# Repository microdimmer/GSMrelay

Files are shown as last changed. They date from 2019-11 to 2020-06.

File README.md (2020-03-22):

# Arduino GSM relay with ring controlling and temp sensors

GSM relay with two temperature sensors, GSM time-synchronization, ring controlling and audio notification. 

## Components

* GSM/GPRS AiThinker A6 
* Arduino Pro Mini, Atmega 328p, 5V/16MHz
* I2C 1602 16X2 Character LCD Module
* Two ds18b20 temperature sensors
* DFPlayer mini MP3 module
* Relay module
* Rotary encoder switch EC11
* Resistors, wires, enclosure

## Photos:


## Libraries

* [Arduino](https://github.com/arduino/Arduino)
* [Forked menu library for 1602](https://github.com/microdimmer/LiquidMenu)
* [I2C support for 1602](https://github.com/johnrickman/LiquidCrystal_I2C)
* [Memory free library for debuging](https://github.com/maniacbug/MemoryFree)
* [Simple timer library](https://github.com/marcelloromani/Arduino-SimpleTimer)
* [Timekeeping library](https://github.com/PaulStoffregen/Time)
* [Library to handle rotary encoder with button](https://github.com/0xPIT/encoder)
* [DFPlayer mini module library](https://github.com/DFRobot/DFRobotDFPlayerMini)
* [OneWire library](https://github.com/PaulStoffregen/OneWire)

## Scheme:
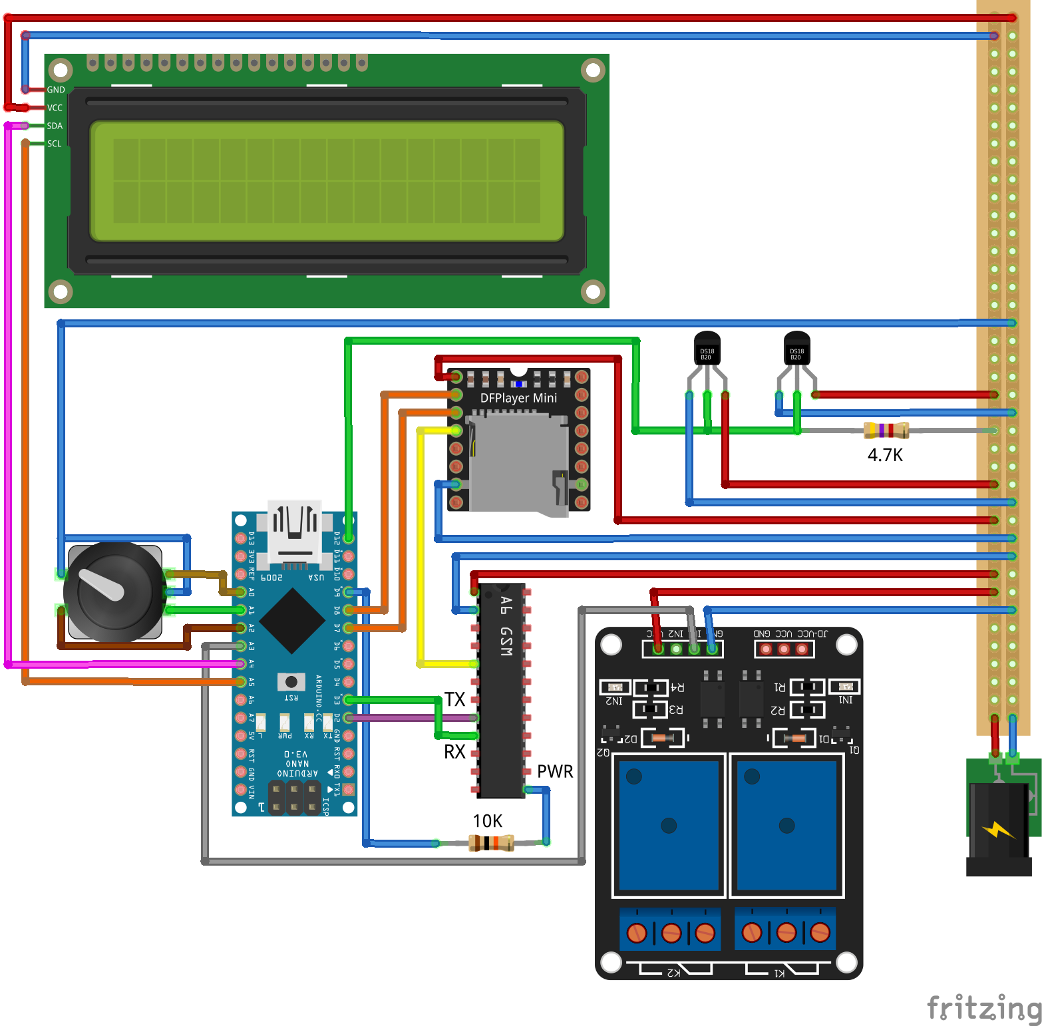
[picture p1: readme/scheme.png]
СХЕМА


## Known issues:

* Relay creates electromagnetic interference which affects the I2C display driver, had to install ferrite bead on I2C data wires.

# Russian:
GSM реле c термостатом, двумя датчиками температуры, автоматизацией по температуре, активацией по телефону и аудио оповещениями.

## Компоненты

* Плата GSM/GPRS AiThinker A6 
* Arduino Pro Mini, Atmega 328p, 5V/16MHz
* Монохромный дисплей I2C 1602 16X2 Character LCD
* Датчик температуры ds18b20 x2
* Модуль воспроизведения MP3 DFPlayer mini 
* Реле 5v
* Энкодер с кнопкой EC11
* кнопки, резисторы, провода, корпус

## Библиотеки

* [Arduino](https://github.com/arduino/Arduino)
* [Forked menu library for 1602](https://github.com/microdimmer/LiquidMenu)
* [I2C support for 1602](https://github.com/johnrickman/LiquidCrystal_I2C)
* [Memory free library for debuging](https://github.com/maniacbug/MemoryFree)
* [Simple timer library](https://github.com/marcelloromani/Arduino-SimpleTimer)
* [Timekeeping library](https://github.com/PaulStoffregen/Time)
* [Library to handle rotary encoder with button](https://github.com/0xPIT/encoder)
* [DFPlayer mini module library](https://github.com/DFRobot/DFRobotDFPlayerMini)
* [OneWire library](https://github.com/PaulStoffregen/OneWire)

## Известные проблемы:

* При переключении GSM-реле на дисплее наблюдались крякозябры из-за электромагнитных помех, пришлось поставить ферритовый фильтры на шину I2C.

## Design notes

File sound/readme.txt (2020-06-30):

1			0001.mp3
2			0002.mp3
3			0003.mp3
4 			0004.mp3
5 			0005.mp3
6 			0006.mp3
7 			0007.mp3
8 			0008.mp3
9 			0009.mp3
10 			0010.mp3
11  		0011.mp3
12			0012.mp3
13			0013.mp3
14			0014.mp3
15			0015.mp3
16			0016.mp3
17			0017.mp3
18			0018.mp3
19			0019.mp3
20			0020.mp3
30			0021.mp3
40			0022.mp3
50			0023.mp3
60			0024.mp3
70			0025.mp3
80			0026.mp3
90			0027.mp3
zero		0028.mp3
minus		0029.mp3
plus		0030.mp3
degree		0031.mp3
degrees		0032.mp3
degrees		0033.mp3
on			0034.mp3 -	джэ эс эм реле привЕтствует! васссс. Вы активировали включение радиатора. Включаем.
off			0035.mp3 -	джэ эс эм реле привЕтствует! васссс. Вы активировали отключение радиатора. Выключаем.
temp_heater 0036.mp3
temp_house 	0037.mp3
balance 	0038.mp3
ruble	 	0039.mp3
rubles		0040.mp3
rubles		0041.mp3
signal_q-ty 0042.mp3
percent 	0043.mp3
percents 	0044.mp3
percents 	0045.mp3
100		 	0046.mp3
200		 	0047.mp3
300		 	0048.mp3
400		 	0049.mp3
500		 	0050.mp3
600		 	0051.mp3
700		 	0052.mp3
800		 	0053.mp3
900		 	0054.mp3
thermos_on  0055.mp3
thermos_off	0056.mp3

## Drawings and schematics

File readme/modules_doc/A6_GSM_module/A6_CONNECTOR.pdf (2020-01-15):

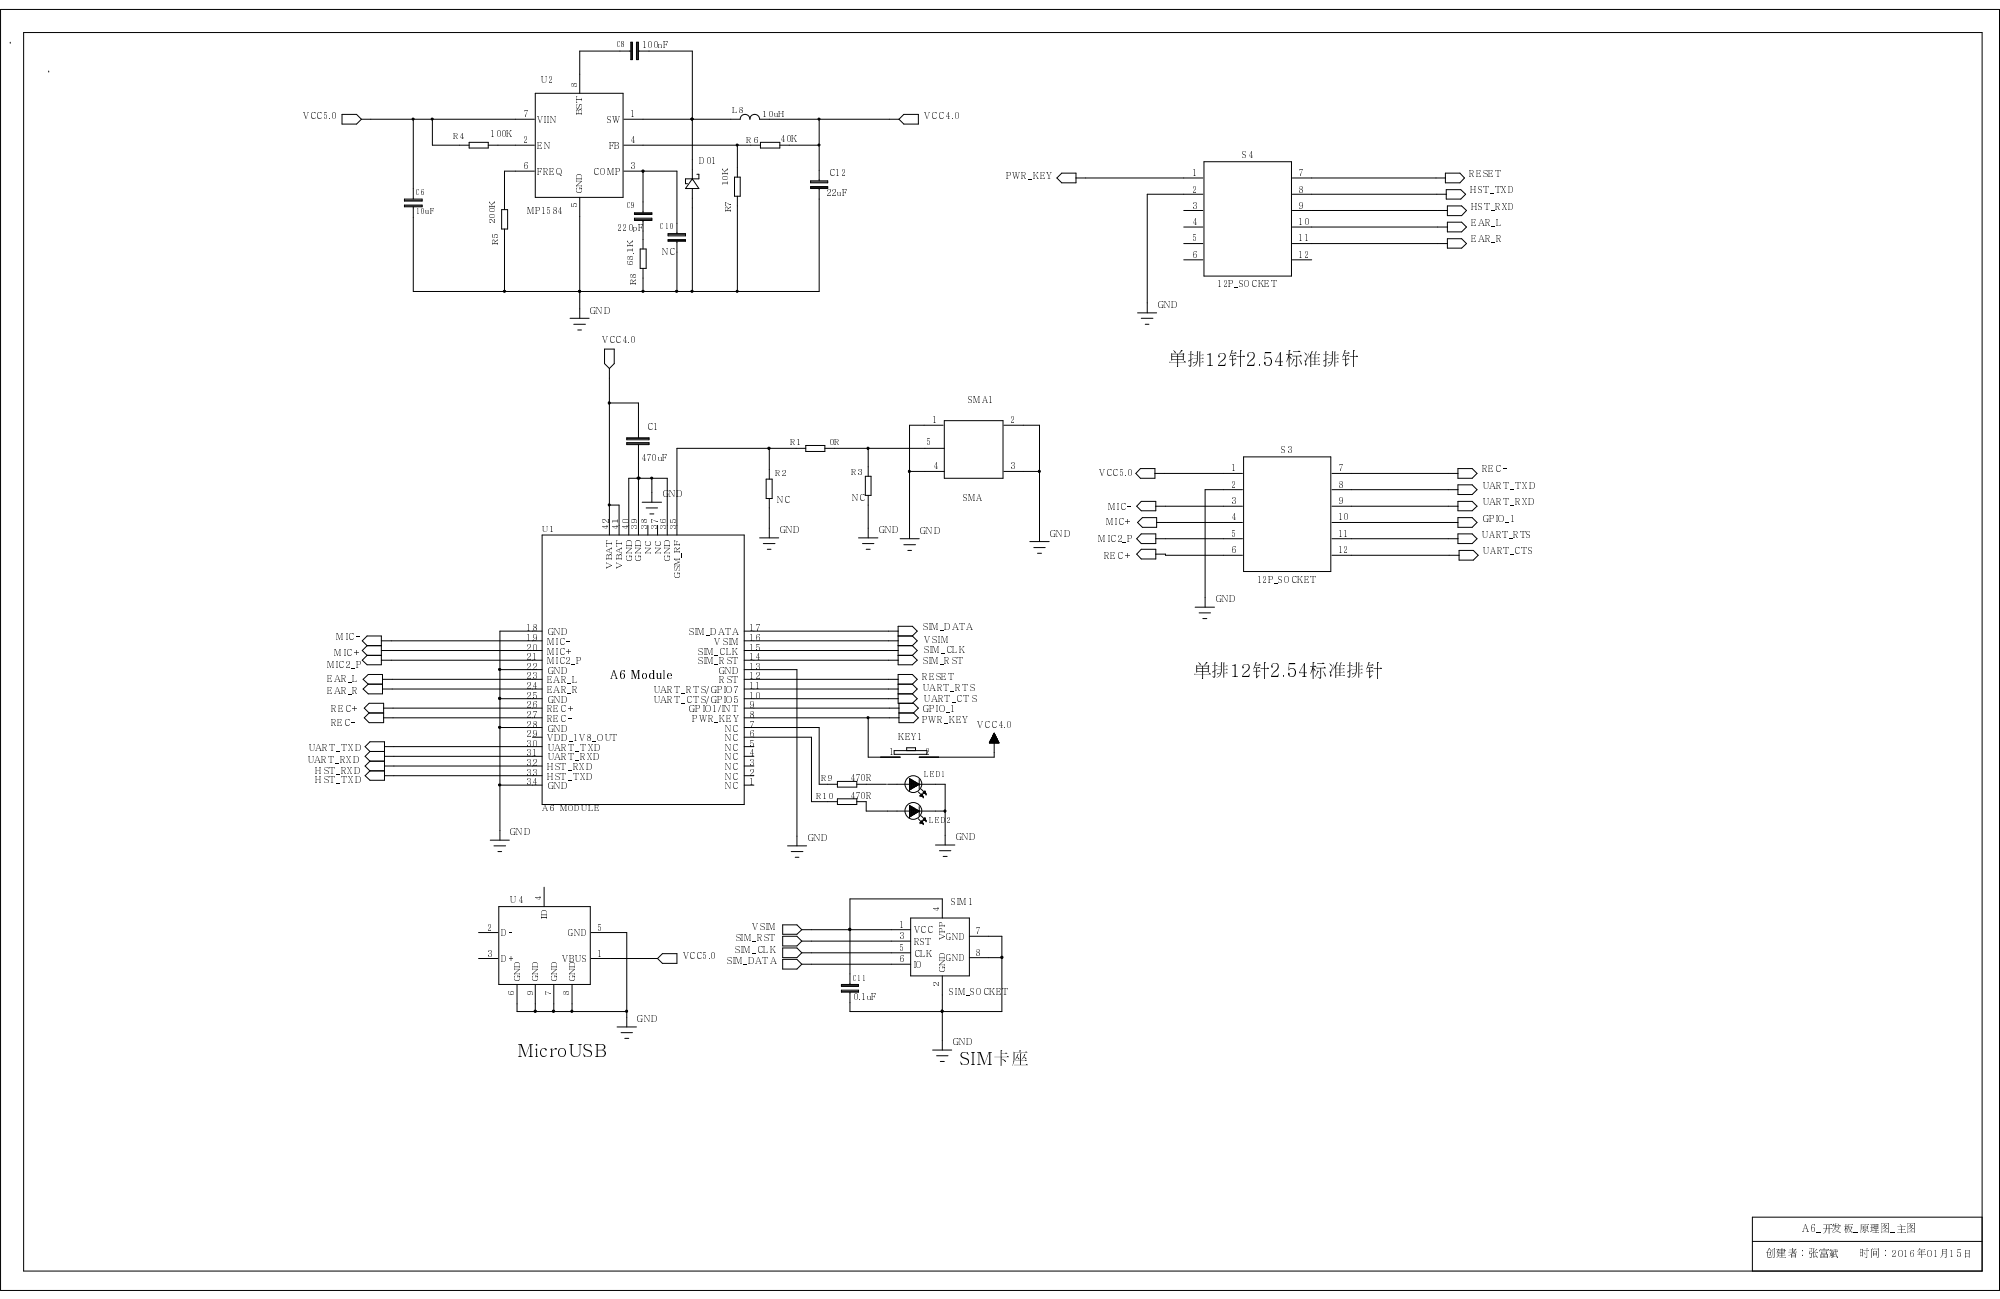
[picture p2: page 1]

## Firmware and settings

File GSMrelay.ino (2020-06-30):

//use DFPlayerMini_Fast, +
//add voice temp information, add read BUSY pin +
//add shedule and temp automation, 
//add preferences menu section, 

//!!!!edit LiquidMenu_config.h first!!!!
/// Configures the number of available variables per line.
// const uint8_t MAX_VARIABLES = 2; ///< @note Default: 5
// /// Configures the number of available functions per line.
// const uint8_t MAX_FUNCTIONS = 1; ///< @note Default: 8
// /// Configures the number of available lines per screen.
// const uint8_t MAX_LINES = 2; ///< @note Default: 12
// /// Configures the number of available screens per menu.
// const uint8_t MAX_SCREENS = 3; ///< @note Default: 14
// /// Configures the number of available menus per menus system.
// const uint8_t MAX_MENUS = 3; ///< @note Default: 8

#define DEBUGGING

const char PROG_VERSION = '3';
const uint8_t RELAY_PIN = A3;                                                                             //pin for Relay
const uint8_t GSM_PIN = 9;                                                                              //pin for GSM
const uint8_t TEMP_SENSOR_PIN = 12;                                                                     //pin for DS18B20
const uint8_t ENCODER_PIN1 = A1;                                                                        //pin for encoder +
const uint8_t ENCODER_PIN2 = A0;                                                                        //pin for encoder -
const uint8_t ENCODER_PIN3 = A2;                                                                        //pin for encoder button
const uint8_t GSM_SERIAL_RX = 2;                                                                        //pin for GSM serial
const uint8_t GSM_SERIAL_TX = 3;                                                                        //pin for GSM serial
const uint8_t MP3_SERIAL_RX = 4;                                                                        //pin for mp3 serial
const uint8_t MP3_SERIAL_TX = 5;                                                                        //pin for mp3 serial
const uint8_t MP3_BUSY = 7;                                                                             //mp3 busy pin
const char PHOME_NUM1[] PROGMEM = {"79227754426"};
const char PHOME_NUM2[] PROGMEM = {"79044719617"};                                                   //pap
const char PHOME_NUM3[] PROGMEM = {"79822219033"};                                                   //pap
const char PHOME_NUM4[] PROGMEM = {"79226505965"};                                                   //tat
const char *const phone_table[] PROGMEM = {PHOME_NUM1, PHOME_NUM2, PHOME_NUM3, PHOME_NUM4}; // phones table 

#include <MemoryFree.h> //https://github.com/maniacbug/MemoryFree TODO del
#include <CircularBuffer.h> // https://github.com/rlogiacco/CircularBuffer //TODO del
#include <OneWire.h>             //for DS18B20
// #include <DFRobotDFPlayerMini.h> //DF MP3 Player mini
#include <DFPlayerMini_Fast.h> //DFPlayer MP3 mini https://github.com/scottpav/DFPlayerMini_Fast
#include <ClickEncoder.h>   //encoder with button https://github.com/0xPIT/encoder
#include <TimeLib.h>        //timekeeping https://github.com/PaulStoffregen/Time
#include <SoftwareSerial.h> //for GSM modem A6 and MP3 module 
#include <SimpleTimer.h>    // Handy timers with callback parameters and polling https://github.com/marcelloromani/Arduino-SimpleTimer
#include <LiquidMenu.h>     //The menu wrapper library https://github.com/microdimmer/LiquidMenu and https://github.com/AlexGyver/GyverLibs/tree/master/microLiquidCrystal_I2C and https://github.com/AlexGyver/GyverLibs/tree/master/microWire
#include <EEPROM.h>         //saving log data to EEPROM and send SMS every 2.5 month

struct Log {
  int8_t home_temp; // temp +- 63, 1 byte, and sentinel, see this https://sites.google.com/site/dannychouinard/Home/atmel-avr-stuff/eeprom-longevity
  int8_t heater_temp; // heater +- 128, 1 byte
  int16_t balance; // balance +-32967, 2 bytes
  time_t unix_time; // current POSIX time, 4 bytes
}; //total 8 bytes (64 bits)

struct Prefs {
  int8_t t_home_set; // temp +- 63, 1 byte, and sentinel, see this https://sites.google.com/site/dannychouinard/Home/atmel-avr-stuff/eeprom-longevity
  int8_t t_heater_set; // heater +- 63, 1 byte, and thermostat flag
  int8_t t_home_hysteresis_set; // home hysteresis +- 128, 1 byte
  int8_t t_heater_hysteresis_set; // heater hysteresis +- 128, 1 byte
}; //total 4 bytes (32 bits)

#define LOGEEPROMSIZE E2END+1 - 256// sizeof(struct Log)*4 = 64*4 = 256;  EEPROM.length() is equal E2END+1

OneWire ds(TEMP_SENSOR_PIN);
byte DSaddr[2][8]; // first and second DS18B20 addresses, home 28FFE44750170473 heater 28FF2FDAC11704DE

ClickEncoder encoder(ENCODER_PIN1, ENCODER_PIN2, ENCODER_PIN3, 2); //changed to 2 at one turn
ClickEncoder::Button button;
int16_t last_val = 0;
int16_t enc_val = 0;

SoftwareSerial gsmSerial(GSM_SERIAL_RX, GSM_SERIAL_TX);
SoftwareSerial mp3Serial(MP3_SERIAL_RX, MP3_SERIAL_TX);
DFPlayerMini_Fast mp3Player;
// DFRobotDFPlayerMini mp3Player;
SimpleTimer timer;
LiquidCrystal_I2C lcd(0x3F, 16, 2);

char GSMstring[64] = {'\0'}; //GSM read string buffer
char string_buff[8] = {'\0'}; //string buffer, used for showing info on display
char phone_buff[12] = {'\0'} ; //phone number string
int8_t temp[2] = {-99, -99}; // temp home, temp heater
int8_t temp_set[2] = {25, 70}; // temp home to set, temp heater to set
int8_t temp_set_hysteresis[2] = {2, 10}; // temp home to set, temp heater to set
int8_t signalStrength = 0; //GSM signal strength
bool GSMonAirFlag = false; //answer call flag
bool GSMwaitReqFlag = false; // waiting request command flag
uint8_t readResponseCounter = 0; // count response commands to run, max 20 times x 500ms
const uint8_t readResponseNum = 20;  //limit 20 times to wait
const uint16_t readResponseTimeout = 500;  //responce timeout to wait
int16_t backlightTimerID = 0;

uint16_t memoryFree = 0;
int16_t balance = -32768; //min uint
CircularBuffer<uint8_t,18> audioQueue;     // audio sequence size, can play five files continuously CircularBuffer<uint8_t,6> audioQueue;
bool workFlag = false;
bool relayFlag = false;
bool thermostatFlag = false; 
bool backlightFlag = true;
bool updateMainScreenFlag = true;
bool clearMainSreenFlag = false;
bool SIMreadyOK = false;
bool GSMinitOK = false;
bool timeSyncOK = false;
bool signalSyncOK = false;
bool balanceSyncOK = false;
bool blinking = true;
uint8_t currentMenu = 0; //0 - homepage, 1 - main menu, 2 - info menu, 3 - temp menu, 4 - set params

#include "menu.h"
#include "debug.h"

void jobThermostat() {
  if (!thermostatFlag || !workFlag)
    return;

  for (uint8_t i = 0; i <= 1; i++) {
    if (temp_set[i] - temp[i] >= temp_set_hysteresis[i]) {
      relayFlag = true;
      digitalWrite(RELAY_PIN, relayFlag);
      PRINTLNF("relay on");
    }
    else {
      relayFlag = false;
      digitalWrite(RELAY_PIN, relayFlag);
      PRINTLNF("relay off");
    }
  }
}

void setup() {
  #ifdef DEBUGGING
  Serial.begin(9600);
  PRINTLNF("Debug on");
  #endif
  
  pinMode(RELAY_PIN, OUTPUT);
  digitalWrite(RELAY_PIN, relayFlag); //relay OFF

  initMenu();
  initMP3(); //mp3 serial port by default is not listening
  initGSM(); //init GSM module, the last intialized port is listening
  initDS();  //init DS temp modules
  requestTempUpdateScreen();  //request temp

  timer.setInterval(1000, requestTempUpdateScreen); //request temp once a second and update screen //TODO separate
  backlightTimerID = timer.setInterval(SECS_PER_MIN * 10000L, backlightOFF); //auto backlight off 10 mins
  
  if (!GSMinitOK) {
    lcd.clear();
    return;
  }
    
  requestBalance();  //request balance from GSM
  waitAndReadUntilOK(balanceSyncOK); //read data response
  requestSignalAndRAM();  //request signal quality from GSM
  waitAndReadUntilOK(signalSyncOK); //read data response
  requestTime(); //request time from GSM
  waitAndReadUntilOK(timeSyncOK); //read data response
  readDSresponse(); //read temp data response
  sendSMSBalance(); //check if its needed to send SMS and then send

  timer.setInterval(10000L, requestSignalAndRAM);        //request signal quality every 10 secs
  timer.setInterval(10000L, jobThermostat);        //do thermostat job
  timer.setInterval(SECS_PER_HOUR * 6000L, requestTime); //sync time every 6 hours
  timer.setInterval(SECS_PER_DAY * 80L, sendSMSBalance); //send sms with balance every 80 days
  timer.setInterval(SECS_PER_HOUR * 6000L, requestBalance);//request balance every 6 hours

  readStringGSM();
  lcd.clear();
  drawMainSreen();
}

void loop() {
  timer.run();
  readButton();
  readEncoder();
  drawMainSreen();
  readStringGSM();
}

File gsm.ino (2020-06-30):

void initGSM() {//TODO
 
  gsmSerial.setTimeout(100); // sets the maximum number of milliseconds to wait for readString()
  
  memset(GSMstring,0,sizeof(GSMstring));
  GSMstring[0] = '\0';
  lcd.setCursor(11, 1);

  #ifdef DEBUGGING
  gsmSerial.begin(9600);
  PRINTINFO("already initialized?");


  for (uint8_t i = 0; i < 4; i++)  {
    gsmSerial.println(F("AT")); 	
    loadingAnimation();
    gsmSerial.println(F("ATE0")); //echo off
    if (gsmSerial.find(strcpy_P(string_buff, PSTR("OK")))) {//copy PROGMEM to buff and find answer in GSM serial
      PRINTLNF("AT ok");
      GSMinitOK = true;
      loadingAnimation();

      gsmSerial.println(F("AT+CSCS=\"HEX\"")); // "GSM","HEX","PCCP936","UCS2
      loadingAnimation();

      cleanSerialGSM();
      return;
    }
  }
  #endif
  
  PRINTINFO("switching GSM");
  pinMode(GSM_PIN, OUTPUT);
  digitalWrite(GSM_PIN, LOW);
  loadingAnimation(4); //wait 2 sec
  digitalWrite(GSM_PIN, HIGH);

  PRINTLNF("");
  PRINTLNF("trying to set 9600");
  gsmSerial.begin(115200);
  for (size_t i = 0; i < 4; i++) {
    gsmSerial.println(F("AT+IPR=9600")); //trying to set 9600
    delay(50);
  }
  gsmSerial.begin(9600);
  
  cleanSerialGSM();
  PRINTINFO("initialize GSM");  
  for (uint8_t i = 0; i < 20; i++) {
    gsmSerial.println(F("AT+CPAS"));
    loadingAnimation();// display loading animation
    gsmSerial.println(F("ATE0")); //echo off
    // gsmSerial.readBytesUntil('\n', GSMstring, sizeof(GSMstring));
    // if (strstr_P(GSMstring, PSTR("+CPAS:0")) != NULL) {
    //   PRINTLNF("AT ok");
    //   GSMinitOK = true;
    //   break;
    // }
    // else {
    //   PRINTLN("GSMstring=",GSMstring);
    // }
    if (gsmSerial.find(strcpy_P(string_buff, PSTR("+CPAS:0")))) {
      PRINTLNF("AT ok");
      GSMinitOK = true;
      break;
    }
  }

  if (!GSMinitOK) {
    PRINTINFO("GSM init error");
    cleanSerialGSM();
    return;
  }

  GSMinitOK = false;
  gsmSerial.println(F("ATE0")); //echo off
  loadingAnimation();
  gsmSerial.println(F("AT+CSCS=\"HEX\"")); // "GSM","HEX","PCCP936","UCS2
  PRINTLNF("waiting for SIM");
  loadingAnimation(10); //5 sec waiting if init first time need
  cleanSerialGSM();
  for (uint8_t i = 0; i < 4; i++)  {
    gsmSerial.println(F("AT+CPIN?")); // Query SIM PIN status
    loadingAnimation(4); //2 sec
    gsmSerial.readBytesUntil('\n', GSMstring, sizeof(GSMstring));
    if (strstr_P(GSMstring, PSTR("+CPIN:READY")) != NULL) { // SIM ok
      PRINTLNF("SIM ok");
      GSMinitOK = true;
      break;
    }
    else if (strstr_P(GSMstring, PSTR("+CME ERROR:10")) != NULL) { //no SIM card
      PRINTLNF("no SIM");
      break;
    }
    else {
      PRINTLN("GSMstring=",GSMstring);
    }
  }
  PRINTLNF("");
  if (GSMinitOK) {
    PRINTLNF("init GSM ok");
  }
  else {
    PRINTINFO("GSM init error");
  }
  
  cleanSerialGSM();
}

void requestTime() { //request time from GSM
  PRINTLNF("request time");
  if (GSMwaitReqFlag || GSMonAirFlag) {
    PRINTINFO("GSM is busy");
    timer.setTimeout(readResponseTimeout,  requestTime);
    return;  
  }
  else {
    GSMwaitReqFlag = true;
    timeSyncOK = false;
    readResponseCounter = 0;
    gsmSerial.println(F("AT+CCLK?"));
    PRINTINFO("send time request");
    timer.setTimeout(readResponseTimeout,  readUntilOK, (void*) &timeSyncOK );
  }
}

void requestSignalAndRAM() {//request signal quality from GSM
  memoryFree = freeMemory();
  //PRINTLN("freeMemory()=", memoryFree);

  //PRINTLNF("request signal strength");
  if (GSMwaitReqFlag || GSMonAirFlag) {
    PRINTINFO("GSM is busy");
    //timer.setTimeout(readResponseTimeout,  requestSignalAndRAM);
    return;  
  }
  else {
    GSMwaitReqFlag = true;
    signalSyncOK = false;
    readResponseCounter = 0;
    gsmSerial.println(F("AT+CSQ")); //request signal quality from GSM
    //PRINTINFO("send signal strength.");
    timer.setTimeout(readResponseTimeout,  readUntilOK, (void*) &signalSyncOK );
  }
}

void requestBalance() {//request balance from GSM
  PRINTLNF("request balance");
  if (GSMwaitReqFlag || GSMonAirFlag) {
    PRINTINFO("GSM is busy");
    timer.setTimeout(readResponseTimeout,  requestBalance);
    return;  
  }
  else {
    GSMwaitReqFlag = true;
    balanceSyncOK = false;
    readResponseCounter = 0;
    gsmSerial.println(F("AT+CUSD=1,\"#105#\",15")); //for requst balance TELE2
    PRINTINFO("send balance request");
    timer.setTimeout(readResponseTimeout,  readUntilOK, &balanceSyncOK ); //PRINTLNHEX("balanceSyncOK hex1=",(long)&balanceSyncOK);
  }
}

void readUntilOK(void* syncOKflag) {//wait and read data response TODODOTODOTODO
  readStringGSM(); //PRINTLNHEX("after readStringGSM hex1=",(long)syncOKflag);
  bool sync_ok_flag = *(reinterpret_cast<bool (*)>(syncOKflag));
  if (sync_ok_flag || (readResponseCounter >= readResponseNum) ) { // max <readResponseNum> times to wait
    GSMwaitReqFlag = false;
    return;
  }
  PRINTINFO("wait");
  timer.setTimeout(readResponseTimeout,  readUntilOK, syncOKflag );
  readResponseCounter++;
}

void waitAndReadUntilOK(const bool &syncOK) { //wait and read data response
    for (uint8_t i = 0; i<21; i++) { 
      timer.run(); //running readUntilOK
      if (syncOK) {
      //  PRINTLNF(".syncOK!");
       return;
      }
      loadingAnimation();
  }
}
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

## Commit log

2018-11-01 0.0.4
    added draft scheme,
    trying to add GSM and MP3
    [scheme.fzz]
2018-11-02 0.0.5
    sheme added
    [scheme.fzz]
2018-11-20 0.0.6
    DS18B20 added
    [scheme.fzz]
2018-11-29 0.0.7
    Relay added, time sync, trying to remove iarduino library
    [scheme.fzz]
2018-12-20 0.1.1
    added second temp sensor
    [scheme.fzz]
2019-05-20 0.2.1
    added voice temp information, added BUSY MP3 module pin
2019-11-23 0.2.5
    added balance check, changed relay pin
2019-11-25 0.2.6
    chahged scheme
    [scheme.fzz]
2020-01-14 0.2.8
    replace display to module with russian character support
    [GSMrelay.ino]
2020-01-24 0.2.8.4
    new SimpleTimer library, disable warnings,
    need to test EEPROM and new timer lib
2020-02-21 0.2.9.4
    test mp3
    http://work-now-dammit.blogspot.com/2016/08/dfplayer-mp3-module-power-onoff-clicks.html
2020-03-07 0.2.11
    minor changes in display screen, decode7bit bugfix
    [GSMrelay.ino]
